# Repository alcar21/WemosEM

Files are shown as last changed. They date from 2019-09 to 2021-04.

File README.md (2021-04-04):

# WemosEM

:warning::warning::warning: **Sorry, I have no time to work on this project. I am involved in new projects** :warning::warning::warning:

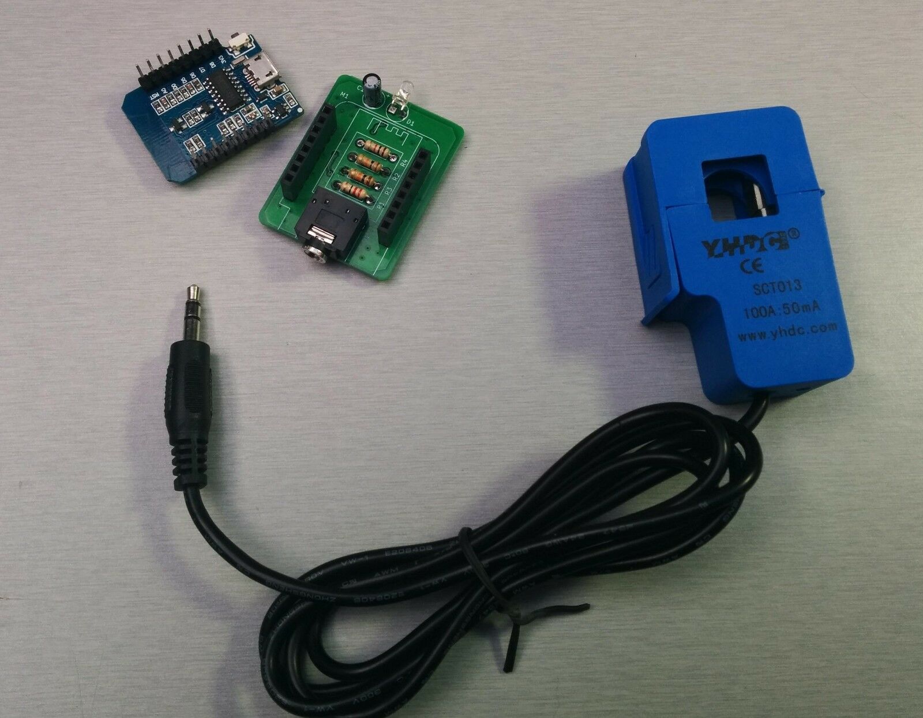
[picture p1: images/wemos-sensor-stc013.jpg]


This is a fork of [@nephiel](https://github.com/Nephiel/MQTT-Power-Sensor) and [@Mottramlabs](https://github.com/Mottramlabs/MQTT-Power-Sensor) projects

Thanks to Dawies [www.domology.es](https://domology.es/medidor-de-consumo-no-invasivo-con-sct013-wemos-d1/) for his contributions and his tutorial

The sensor uses a Wemos D1 Mini and PRO and a Non-invasive Split Core Current Transformer type 100A SCT-013-000, available on eBay.
You can use Current Transformer type calibrated SCT-013-030 (30A), SCT-013-050 (50A) and others. Recomended Clamp 30A or higger.

The sensor samples the current value every 10 seconds and publishes it to a topic via an MQTT broker. you can change this value up to 5 seconds
If the connection fails, it attempts to reconnect to the WiFi and/or the MQTT Broker as needed.

Original Gerber files for the PCB layout and the source files for Kicad are included, although there may be issues with the custom libraries used.

**Software features:**

- Easy setup.
- Responsive design.
- Home Asisstant Discovery.
- All setup in web browser: Wifi, MQTT, Calibrate, timezone, update and system.
- Update Voltaje by MQTT topic.
- NTP to setup timezone.
- Blynk Integration
- ThingSpeak integration
- OTA updates
- Optional reset Kwh counter one day of the month
- Reset Kwh in MQTT Topic

#### Components: 
- Wemos D1 Mini / D1 Mini Pro
- [ESP8266 Mains Current Sensor](https://www.ebay.es/itm/ESP8266-Mains-Current-Sensor-Wemos-Current-transformer-SCT013-100A-50mA/133077015640)
- Current transformer SCT013 (Ebay or Aliexpress)
- Optional case: https://www.thingiverse.com/thing:3544702

**WARNING:** If you use calibrated clamp, **REMOVE resistance R1** from mains current sensor.

## Firmware installation and first setup

#### Flashing: 

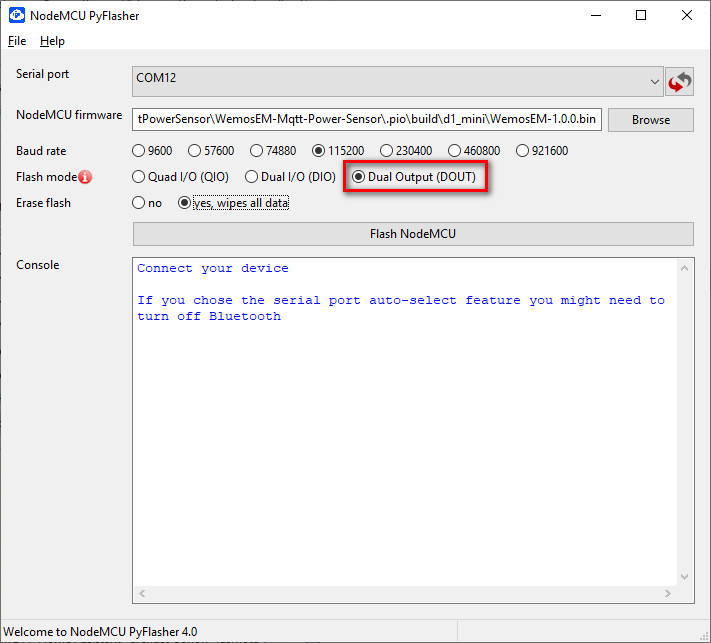
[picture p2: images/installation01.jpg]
installation01


Download latest [release](https://github.com/alcar21/WemosEM/releases)
You can flash using software [nodemcu-pyflasher](https://github.com/marcelstoer/nodemcu-pyflasher/releases)

1. Select Serial port (COM# port) where your serial-to-USB or NodeMCU/D1 mini is connected. Leave on auto-select if not sure.
2. Browse to the binary you downloaded from WemosEM releases.
3. Set Baud rate to 115200 and **Flash mode to DOUT**. Erase flash to **yes** if it is the first time flashing WemosEM on the device or you're experiencing issues with existing flash. If you're upgrading WemosEM set to no.
4. Click Flash NodeMCU and watch the progress in console.

If the flash was successful the console will display:
  Firmware successfully flashed. unplug/replug or reset device to switch back to normal boot mode

Unplug your adapter or device and plug it back in or connect to another power source. Your device is now ready for Initial configuration.

You can see in Tasmota project other options to flash: https://github.com/arendst/Sonoff-Tasmota/wiki/Flashing

#### Initial configuration

WemosEM provides a wireless access point for easy Wi-Fi configuration.

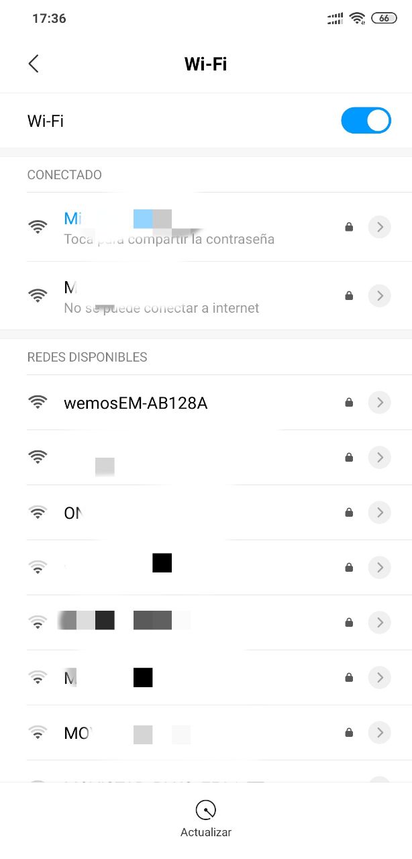
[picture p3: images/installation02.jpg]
installation02

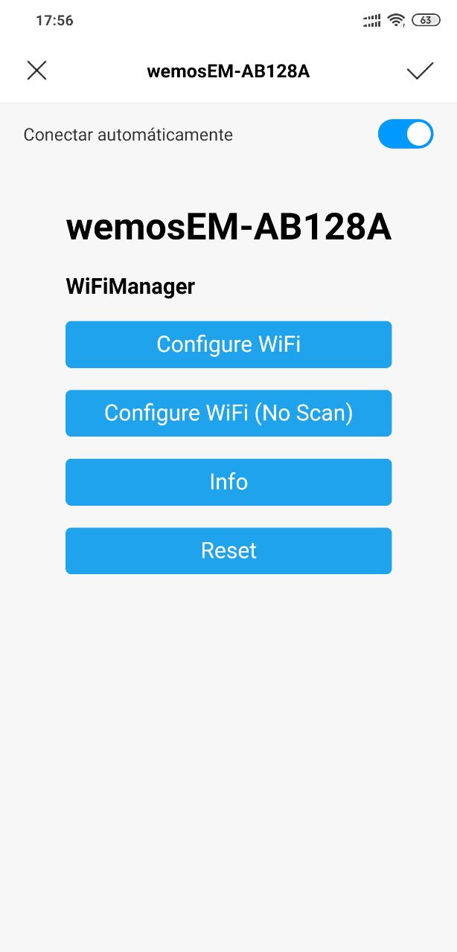
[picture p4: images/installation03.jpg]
installation03

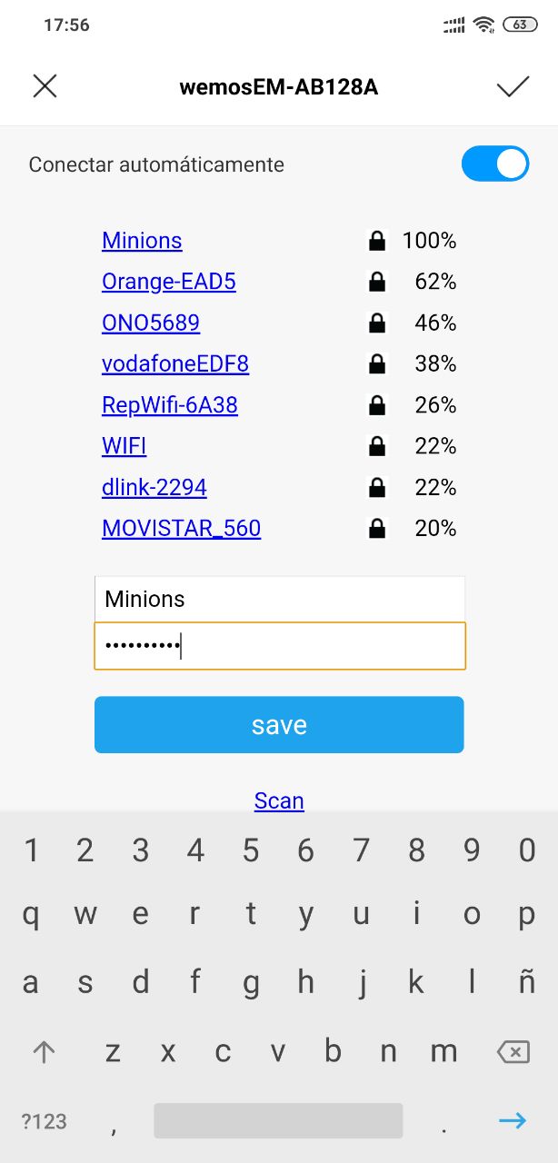
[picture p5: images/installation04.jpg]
installation04


Connect your device to a power source and grab your smartphone (or tablet or laptop or any other web and Wi-Fi capable device). Search for a Wi-Fi AP named **wemosEM-xxxxxx** (where x is a last part of MAC) and connect to it with password **infinito&masalla**. In this example the Wi-Fi AP is named **wemosEM-AB128A**. When it connects to the network, you may get a warning that there is no Internet connection and be prompted to connect to a different network. Do not allow the mobile device to select a different network.

After you have connected to the WemosEM Wi-Fi AP, open http://192.168.4.1 in a web browser on the smartphone (or whatever device you used). Some devices might prompt you to sign in to Wi-Fi network which should also open the above address.

At this page you can have WemosEM scan for available Wi-Fi networks. Select and setup you wifi network. Click save and you wemos will connect to your wifi.

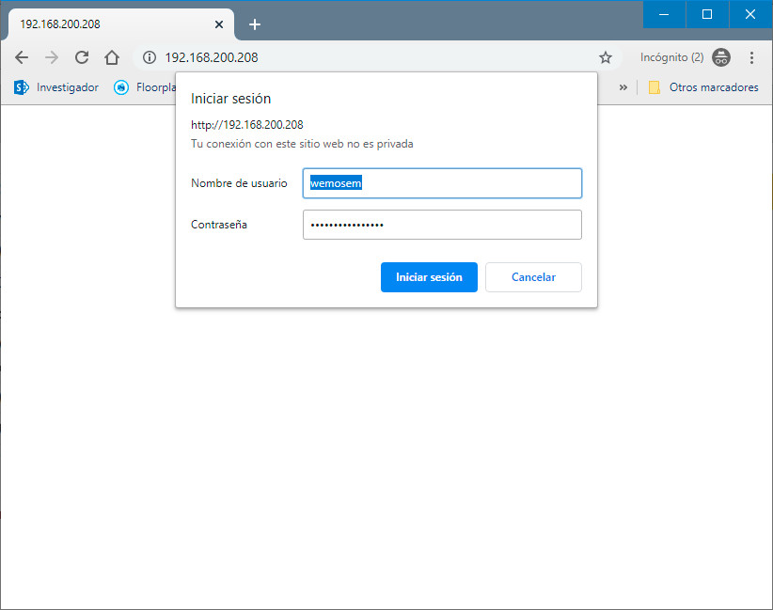
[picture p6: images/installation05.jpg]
installation05

Finally, connect with IP or http://wemosem-xxxxxx.local/ and enter default user and passwor:

* **Default user: wemosem**
* **Default password: infinito&masalla**

Password is updatable in configuration system tab.

## Ical Value

you can view the ICAL value in http://lechacal.com/wiki/index.php/Current_Transformer_Conditioner

CT | Output Type | Rburden | Rgain (for 5V) | ICAL (for 5V) | Rgain (for 3.3V) | ICAL (for 3.3V)
-- | -- | -- | -- | -- | -- | --
SCT-013-005 | Voltage | None | 130 kΩ | 2.83 | None* | 5.0
SCT-013-010 | Voltage | None | 130 kΩ | 5.66 | None* | 10.0
SCT-013-015 | Voltage | None | 130 kΩ | 8.49 | None* | 15.0
SCT-013-020 | Voltage | None | 130 kΩ | 11.31 | None* | 20.0
SCT-013-025 | Voltage | None | 130 kΩ | 14.14 | None* | 25.0
SCT-013-030 | Voltage | None | 130 kΩ | 16.96 | None* | 30.0
SCT-013-050 | Voltage | None | 130 kΩ | 28.28 | None* | 50.0
SCT-013-060 | Voltage | None | 130 kΩ | 33.94 | None* | 60.0
  |   |   |   |  
SCT-006 | Current | 10 Ω | 17 kΩ | 11.62 | 28 kΩ | 17.5
SCT-013-000 | Current | 10 Ω | 40 kΩ | 56.57 | 75 kΩ | 85.71
SCT-019 | Current | 10 Ω | 24 kΩ | 116.13 | 40 kΩ | 171.43

## Setup in Home Assistant (without MQTT autodiscovery)
    
    sensor:
    - platform: mqtt
      state_topic: "wemos/wemosEM-XXXXXX/power"
      name: WemosEM-Amperaje
      icon: mdi:current-ac
      unit_of_measurement: "A"
      value_template: "{{ value_json.current }}"
    - platform: mqtt
      state_topic: "wemos/wemosEM-XXXXXX/power"
      name: WemosEM-Consumo Actual
      icon: mdi:power-plug
      unit_of_measurement: "W"
      value_template: "{{ value_json.watios }}"
    - platform: mqtt
      state_topic: "wemos/wemosEM-XXXXXX/power"
      name: WemosEM-KWh
      icon: mdi:power-plug
      unit_of_measurement: "KWh"
      value_template: "{{ value_json.kwh }}"nt Cell  | Content Cell  |

## Update Voltaje with Home Assistant

if you have a Shelly EM, add a automation in Home assistant:
      
      - alias: Update voltage WemosEM
        initial_state: 'on'
        trigger:
        - platform: mqtt
          topic: shellies/shellyem-B9E2E9/emeter/0/voltage
    
        action:
        - service: mqtt.publish
          data_template:
            topic: "wemos-cmd/wemosEM-XXXXXX/voltage"
            payload: '{{ trigger.payload }}'

if you have a device with Tasmota, add a automation in Home assistant:

      - alias: Update voltage Tasmota-WemosEM
        initial_state: 'on'
        trigger:
        - platform: mqtt
          topic: tele/sonoff01/SENSOR

        action:
        - service: mqtt.publish
          data_template:
            topic: "wemos-cmd/wemosEM-XXXXXX/voltage"
            payload: "{{ trigger.payload_json['ENERGY'].Voltage }}"

## Blynk Integration

Go to Blynk app on your phone and layout the blynk project with virtual pin number according:
- Virtual PIN V0: Voltage (V)
- Virtual PIN V1: Current (A)
- Virtual PIN V2: Live Watios (w)
- Virtual PIN V3: Energy (kwh)
- Virtual PIN V4: Energy before last reset (kwh)

Setup in web interface token auth, optional you can setup server and port server.

## Thingspeak Integration
Setup in web interface token auth (Write API Key) and Channel number. 
- Field 1: Voltage (V)
- Field 2: Current (A)
- Field 3: Live Watios (w)
- Field 4: Energy (kwh)
- Field 5: Energy before last reset (kwh)

## MQTT Topics
Topic  | Description
------------- | -------------
wemos-cmd/wemosEM-XXXXXX/voltage | Set/update voltage (from sonoff, shelly or other devices)
wemos-cmd/wemosEM-XXXXXX/status | Get Status of wemosEM
wemos-cmd/wemosEM-XXXXXX/resetkwh | reset kwh and store and beforeResetkwh variable

## OTA Updates
OTA updates from platformio windows with espota:
~/.platformio/packages/tool-espotapy/espota.py --progress --ip 192.168.4.1 --auth "infinito&masalla" --file wemosEM-1.3.1_core-2.4.bin

## Developers
This project is developed with **platformio**. WemosEM not compile with core 2.3 because blynk library require core 2.4.0 or higher.
- Recomended compile this project with Arduino Core 2.4.2.

**Commands:**
- Compile: pio run
- Compile and upload Wemos D1: pio run -t upload

Other options:
- Compile with core 2.5: pio run -t upload -e d1_mini_2_5
- Compile for Wemos D1 Mini PRO (**only core 2.4**): pio run -t upload -e d1_mini_pro_2_4

## Tests

## Screenshots

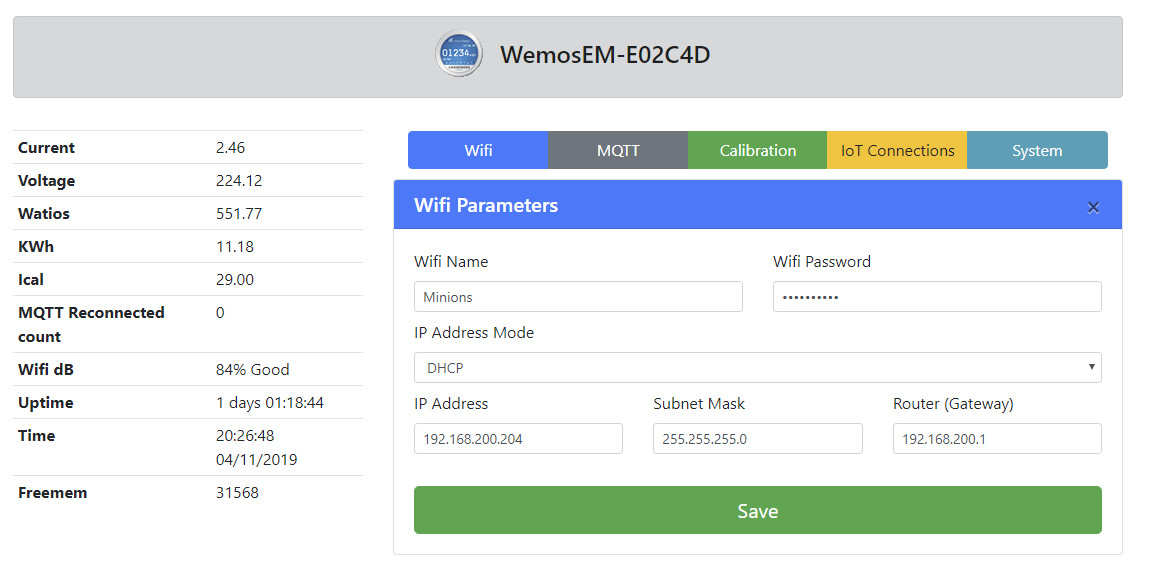
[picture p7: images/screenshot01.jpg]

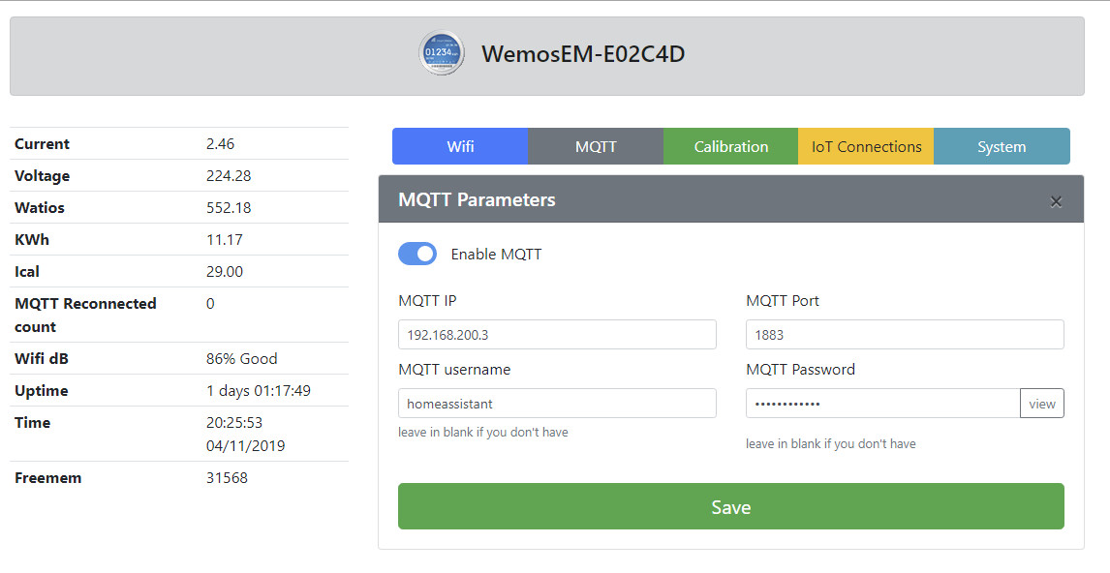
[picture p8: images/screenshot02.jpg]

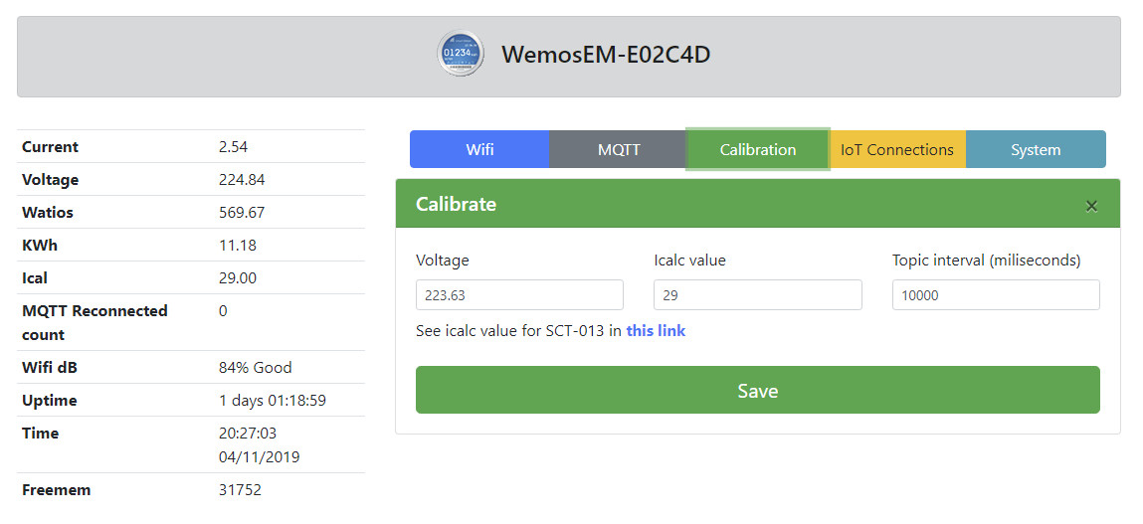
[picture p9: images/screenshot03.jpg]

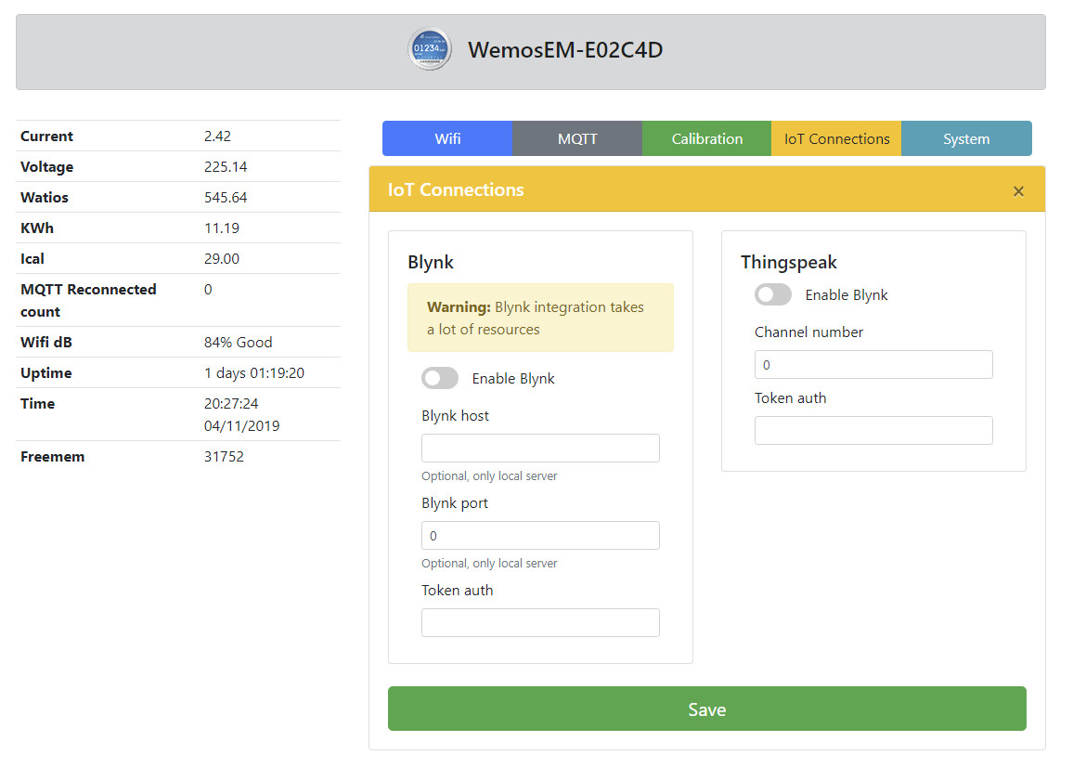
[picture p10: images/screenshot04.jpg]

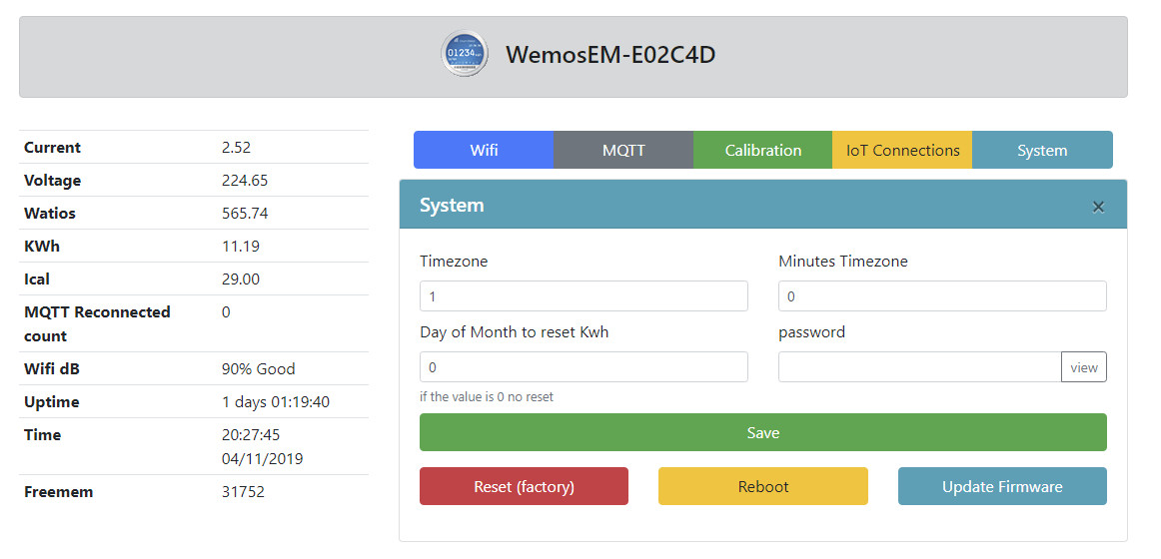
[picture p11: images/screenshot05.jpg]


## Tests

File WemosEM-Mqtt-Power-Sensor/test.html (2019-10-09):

#### WemosEM-000000

Current | 0.00
Voltage | 0.0
Watios | 0.00
KWh | 0.00
Ical | 0.00
MQTT Reconnected count | 0
Wifi dB | 0
Uptime | 0 days 00:00:00
Time | 00:00:00 00/00/0000
Freemem | 0

Wifi MQTT Calibration Time System

##### Wifi Parameters

Wifi Name

Wifi Password

IP Address Mode

IP Address

Subnet Mask

Router (Gateway)

Save

##### MQTT Parameters

Enable MQTT

MQTT IP

MQTT Port

MQTT username leave in blank if you don't have

MQTT Password

view

leave in blank if you don't have

Save

##### Calibrate

Voltage

Icalc value

Topic interval (miliseconds)

See icalc value for SCT-013 in this link (http://lechacal.com/wiki/index.php/Current_Transformer_Conditioner)

Save

##### Time

Timezone

Minutes Timezone

Save

##### System

password

view

Save

Reset (factory)

Reboot

Update Firmware

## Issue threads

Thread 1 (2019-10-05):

platformio compile problems

dpavlin, 2019-10-05:
First, thanks for such a nice project. I'm having problems compiling using PlatformIO, version 4.0.3 (which is currently latest). When using (default) platform_150 it doesn't fit:

```
/home/dpavlin/.platformio/packages/toolchain-xtensa@1.40802.0/bin/../lib/gcc/xtensa-lx106-elf/4.8.2/../../../../xtensa-lx106-elf/bin/ld: .pio/build/d1_mini/firmware.elf section `.text' will not fit in region `iram1_0_seg'
collect2: error: ld returned 1 exit status
*** [.pio/build/d1_mini/firmware.elf] Error 1
```

And when compiling with all others I get:

```
Setup finished

Exception (3):
epc1=0x4021c03c epc2=0x00000000 epc3=0x00000000 excvaddr=0x4025c5d7 depc=0x00000000
```
And esp keeps rebooting.

Your release binary does work for me, so I'm wondering how did you compile it?

alcar21, 2019-10-07:
Please, compile with platform_180. I fix as soon as possible.
In the current download of the arduino versions two files are missing. You can download them from here: https://github.com/esp8266/Arduino/tree/2.3.0/tools/sdk/ld
The files are: eagle.flash.4m3m4s.ld and eagle.app.v6.common.ld
I will correct it later.

alcar21, 2019-10-07:
Sorry, fixed in master branch.

Closed 2019-10-07.

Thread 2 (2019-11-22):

MQTT not publishing

afly007, 2019-11-22:
I'm having issues with MQTT and home assistant.  The only message that the MQTT broker receives from wemosEM is a status offline message, even though the logs show it's publishing correctly.

I have everything configured as instructed in the Readme, any ideas?

Thanks

Status MQTT: -3 Reconnecting...
 Attempting MQTT Broker connection... Reconnecting with user/pass
 MQTT Connected.
Preparing topic HA Discover
Preparing message HA Discover
 [METER] - Payload: {"current":"0.00","voltage":"5.00","watios":"0.00","kwh":"0.02","beforeKwh":"0.00","ical":"85.71","mqttreconnected":"2","wifidb":"56% Bad","uptime":"   0 days 00:02:32","time":"11:36:30 22/11/2019","freemem":23928}
 [MQTT] - Published: wemos/wemosEM-51F13F/power > {"current":"0.00","voltage":"5.00","watios":"0.00","kwh":"0.02","beforeKwh":"0.00","ical":"85.71","mqttreconnected":"2","wifidb":"56% Bad","uptime":"   0 days 00:02:32","time":"11:36:30 22/11/2019","freemem":23928}
 [MQTT] - Published: wemos/wemosEM-51F13F/status > online [METER] - rmsCurrent: 0.00 mainsVoltage: 5.00 Watios: 20.36 kwh: 0.02 Before reset kwh: 0.00 lastTimeMeasure: 147133
SAVED CONFIG: {"wifi_name":"","wifi_password":"","ip_mode":0,"ip":"192.168.0.43","mask":"255.255.255.0","gateway":"192.168.0.1","mqtt_enabled":true,"mqtt_server":"192.168.0.6","mqtt_port":1883,"mqtt_username":"wemosem","mqtt_password":"wemosem","message_interval":10000,"voltage":5,"ical":85.71,"blynk_enabled":false,"blynkAuth":"","blynkServer":"","blynkPort":0,"ts_enabled":false,"tsChannelNumber":0,"tsWriteAPIKey":"","timezone":7,"minutes_timezone":0,"system_password":"infinito&masalla","dayReset":0,"watiosTotal":20.35835,"kiloWattHours":0.020358,"beforeResetKiloWattHours":0}
[BLYNK] Disabled
[THINGSPEAK] Disabled
 [METER] - Payload: {"current":"0.00","voltage":"5.00","watios":"0.00","kwh":"0.02","beforeKwh":"0.00","ical":"85.71","mqttreconnected":"2","wifidb":"60% Poor","uptime":"   0 days 00:02:37","time":"11:36:35 22/11/2019","freemem":26200}
 [MQTT] - Published: wemos/wemosEM-51F13F/power > {"current":"0.00","voltage":"5.00","watios":"0.00","kwh":"0.02","beforeKwh":"0.00","ical":"85.71","mqttreconnected":"2","wifidb":"60% Poor","uptime":"   0 days 00:02:37","time":"11:36:35 22/11/2019","freemem":26200}
 [MQTT] - Published: wemos/wemosEM-51F13F/status > online

Output from Home Assistant MQTT listener...

 Message 18 received on wemos/wemosEM-51F13F/status at 11:39 PM:

Offline

QoS: 0 - Retain: false
Message 17 received on wemos/wemosEM-51F13F/status at 11:39 PM:

Offline

QoS: 0 - Retain: false
Message 16 received on wemos/wemosEM-51F13F/status at 11:38 PM:

Offline

QoS: 0 - Retain: false
Message 15 received on wemos/wemosEM-51F13F/status at 11:37 PM:

Offline

QoS: 0 - Retain: false
Message 14 received on wemos/wemosEM-51F13F/status at 11:36 PM:

Offline

alcar21, 2019-11-22:
Hello,
what version do you have installed?
- WemosEM-1.3.1-core_2.4.bin?
- WemosEM-1.3.1-core_2.5.bin?

Do you have the discover on home assistant enabled?

Thanks.

Closed 2019-12-31.

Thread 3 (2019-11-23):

MQTT not enabled after reboot

mason-xx, 2019-11-23:
Flashed WemOS D1  mini with WemosEM-1.3.1-core_2.5.bin. Configured and enabled MQTT on the Webif. Working fine. But after disconnect the Wemos aka reboot it, MQTT stays disabled and need to be reenabled by the webif to work again.

Expected behaviour would be to stay activated after a reset/reboot of the controller.

alcar21, 2019-11-23:
Please, use version WemosEM-1.3.1-core_2.4.bin.
The arduino 2.5 core has problems with the Wifi controller. I have read it on the [Tasmota website](https://github.com/arendst/Tasmota/releases) **search** "Core version 2.3.0 vs 2.4.2 vs 2.5.2"

The core 2.4 in this firmware working fine. Please, can you attach the logs if you know how to obtain them?

> Expected behaviour would be to stay activated after a reset/reboot of the controller.
yes, this is how it works for me with WemosEM-1.3.1-core_2.4.bin. I honestly haven't tried the version with core 2.5.

Thank you.

mason-xx, 2019-11-23:
You want the logs of the 2,5 version or the 2.4?

alcar21, 2019-11-23:
The test performed by other developers, the version 2.4 is usually more stable. The best core is 2.3 but there are libraries that use firmware that does not support 2.3.
You can attach the logs of the version you want but I recommend you use the 2.4

mason-xx, 2019-11-23:
Here is a log from 2.5 https://hastebin.com/awoqifehiz.cs not much in there..
But after reflashing with 2.4 mqtt stays enabled after a reboot as expected... thank you! :)

alcar21, 2019-11-24:
Great!
Log is only necessary when the problem occurs but it is fully proven to fail.
Thank you very much.

Closed 2019-11-24.

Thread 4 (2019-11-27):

Domoticz integration

InvertedMinor, 2019-11-27:
Could you provide a Domoticz integration via MQTT?

alcar21, 2019-11-28:
Ok, I Try. I have not Domoticz .

InvertedMinor, 2019-11-28:
Great:  https://www.domoticz.com/wiki/MQTT

alcar21, 2019-11-28:
it is easy. Please, Can you do beta tester??
Thanks!

InvertedMinor, 2019-11-29:
of course!

asem67, 2019-12-31:
Could you provide a Domoticz integration via MQTT
or IoT Connections >> [Domoticz API](https://www.domoticz.com/wiki/Domoticz_API/JSON_URL%27s#Electricity_.28instant_and_counter.29)

Thanks !

alcar21, 2019-12-31:
Hello,
I'm working in it. in the next few days I will release a version compatible
with domoticz
Thanks

El mar., 31 dic. 2019 18:23, asem67 <notifications@github.com> escribió:

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

pepijnkoopman, 2020-01-12:
Looking forward to the Domoticz integration via MQTT! When it's is ready I would like to beta test as well.

RichieRogers, 2020-05-11:
Hi,
It looks like development has stopped on this :(
Has anyone successfully integrated this with Domoticz (ideally with MQTT)?
If so, can you supply the firmware or what modifications i need to make to WemosEM to get this working?

Thanks,
Richie

pepijnkoopman, 2020-05-11:
Hi Richie, I integrated WemosEM with Domoticz using **MQTT + Node-RED**. WemosEM publishes the data on a MQTT server (Mosquitto). A Node-RED script subscribes to these messages on Mosquitto server, converts them to messages for Domoticz and publishes the messages to the domoticz/in topic of the MQTT server of Domoticz. More information: https://www.domoticz.com/wiki/MQTT

RichieRogers, 2020-05-11:
Ahh, ok.
I'm running Domoticz and Mosquitto on a Windows environment, so will look at installing Node-Red as well (no experience of Node-Red so will be interesting getting this working).

Thanks,
Richie

pepijnkoopman, 2021-05-26:
Hi @daniel-dms, below is the export of my Node-Red flow:
`[{"id":"3f2dd754.b751f","type":"tab","label":"PowerMon1 Current","disabled":false,"info":""},{"id":"40a67cbc.ee3d74","type":"mqtt in","z":"3f2dd754.b751f","name":"","topic":"wemos/wemosEM-239E74/power","qos":"0","datatype":"auto","broker":"bbc5f10.1ab581","x":170,"y":60,"wires":[["da04248a.acb1a"]]},{"id":"da04248a.acb1a","type":"json","z":"3f2dd754.b751f","name":"","property":"payload","action":"","pretty":false,"x":350,"y":220,"wires":[["a14cc7d1.c7e93"]]},{"id":"a14cc7d1.c7e93","type":"function","z":"3f2dd754.b751f","name":"Get current","func":"var value = msg.payload.current;\nmsg.payload = value;\nreturn msg;","outputs":1,"noerr":0,"x":530,"y":220,"wires":[["9769d2ff.7a808","f3521a2e.f786e8"]]},{"id":"709c2826.f4fb28","type":"mqtt out","z":"3f2dd754.b751f","name":"","topic":"domoticz/in","qos":"","retain":"","broker":"72fca658.733588","x":1030,"y":60,"wires":[]},{"id":"e750ff81.9554d","type":"debug","z":"3f2dd754.b751f","name":"","active":true,"tosidebar":true,"console":false,"tostatus":false,"complete":"payload","targetType":"msg","x":990,"y":300,"wires":[]},{"id":"9769d2ff.7a808","type":"debug","z":"3f2dd754.b751f","name":"","active":false,"tosidebar":true,"console":false,"tostatus":false,"complete":"payload","targetType":"msg","x":690,"y":300,"wires":[]},{"id":"f3521a2e.f786e8","type":"function","z":"3f2dd754.b751f","name":"Add Domoticz IDX 33 (PowerMon1Current)","func":"var current = msg.payload;\n\nmsg.payload = {};\nmsg.payload.svalue = current;\nmsg.payload.idx = 33;\nreturn msg;","outputs":1,"noerr":0,"x":870,"y":220,"wires":[["e750ff81.9554d","709c2826.f4fb28"]]},{"id":"bbc5f10.1ab581","type":"mqtt-broker","name":"SDRPi","broker":"192.168.2.31","port":"1883","clientid":"","usetls":false,"compatmode":true,"keepalive":"60","cleansession":true,"birthTopic":"","birthQos":"0","birthPayload":"","closeTopic":"","closePayload":"","willTopic":"","willQos":"0","willPayload":""},{"id":"72fca658.733588","type":"mqtt-broker","name":"","broker":"192.168.2.48","port":"1883","clientid":"","usetls":false,"compatmode":false,"keepalive":"15","cleansession":true,"birthTopic":"","birthQos":"0","birthPayload":"","closeTopic":"","closePayload":"","willTopic":"","willQos":"0","willPayload":""}]`

daniel-dms, 2021-05-26:
THANKS.........IT'S WORKING

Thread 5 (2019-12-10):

Differences between SCT-013-000

silbopower, 2019-12-10:
Hi alcar21, first of all, great work! I'm going to use it ASAP but I have a dubt.
What is the difference using a 30A transformer or a 50A one?
Could I also use freely a 15A or I have to modify some configuration (sw/hw)?
Thank you
S

alcar21, 2019-12-10:
Hello,
Thank :smiley:. yes, you can perfectly use the 50A, 30A or 15A transformer. There is no problem. Only the calibration changes in the "Ical Value" section

silbopower, 2019-12-11:
Great! I'll try as soon as components arrive!
Thanks again

Closed 2019-12-31.

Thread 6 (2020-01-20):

A couple of minor items and a question

NorthernMan54, 2020-01-20:
Tks for this piece of work, it is very well done.  I just have a couple of minor things

1 - I'm in North America and I can't set the timezone to -5 ( Eastern Standard )

2 - When the device reboots, the data is wonky for the first minute, can this false data be thrown away?  ie call em_read(true); at the end of the setup function?

3 - When Power usage is zero, the current sits between 0.02 to 0.04, any thoughts on why?

4 - Noticed that after running for 24 hours, this message "Failed to open config file for writing", so am wondering why the em_read is writing the config after every read in WiFi station mode.

For setup, I'm using a SCT013 Calibrated at 30A 1V, local power is 120 volt 60 Hertzs

alcar21, 2020-01-22:
Hello, thanks.

1. Ok, i will fix in next version.
2. It's difficult, when system start, it perform a calibration and discard initials values. I could add an option in configuration that discard data of a period of time
3. It is the rounding of precision, it will really count for example 0.004 watts
4. Which version are you using? Please use the core 2.4

The measured is correctly? Thanks by the report.
Please be patient, my dedication time to the project is very short.

NorthernMan54, 2020-01-22:
For these, I'm putting together a pull request and fix for the MQTT Issue

I'm just testing behaviour when WiFi drops and restarts, then I will submit

alcar21, 2020-01-22:
Thank you.

Un saludo,
Alfonso C.

El jue., 23 ene. 2020 a las 0:20, Northern Man (<notifications@github.com>)
escribió:

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

NorthernMan54, 2020-01-23:
Please review pull request #8

alcar21, 2020-01-23:
Accepted. Thanks.

NorthernMan54, 2020-01-23:
Tks

Closed 2020-01-23.

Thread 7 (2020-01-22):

MQTT gets disabled after a reboot

amoros1, 2020-01-22:
Congrats for the nice piece of work!

I found that after enabling MQTT and saving in the MQTT parameters, when the Wemos restarts, the MQTT gets disabled so you need to enter again in the UI to enable it. I wonder if there is some issue with the enable flag that after a reboot it is set again to disable?.
Could be this behavoir the way this function was designed to work?,

Many thanks
Luis

alcar21, 2020-01-22:
:smirk: yes, this error has been reported by other people in private. I'm working in it.

if yoy want try, in the previous version if it works correctly, I am checking it.

Thanks, regards.

amoros1, 2020-01-24:
Thanks. Yes, I will make the test
Regards

plutec, 2020-04-06:
Are working in the previous version? Did you fix it in the new one?

Thanks!

alcar21, 2020-04-06:
Sorry, I have yet to release the patch. This week i try it.

PaulHam211, 2020-04-21:
Hey, Any chance of releasing the patch for this? I have set up my device today and have noticed that MQTT disables after a reset.
I considered trying to build a version with MQTT enabled in code however I struggled to build in Atom (mac equivalent of Platform IO) and now I assume this is a bug and enabling MQTT automatically wont actually fix it?

nandosof, 2020-05-14:
have fix?? thank you!

alcar21, 2020-06-02:
Sorry, I will release a version this weekend.

I don't have much time to dedicate to the project.

Thanks you

PaulHam211, 2020-06-21:
Sorry @alcar21  I know your busy but any luck with this MQTT enable on boot fix?

plutec, 2020-07-06:
Fixed in code, I just compile for Core 2.4. I didn't check yet in my hardware.

https://mega.nz/file/eRknmQKQ#T9rFCZ6qjTx1qB8fpxCNPB3yId9L3Dg5LpY-535Yt5k

plutec, 2020-07-06:
I just checked in my wemos and at least it saves the MQTT after restart. So this flaw can be considered as solved.

nandosof, 2020-07-06:
Work fine. Thanks for your work!

rechena, 2020-10-04:
I can confirm that on the latest version this issue still happens :(

plutec, 2020-11-01:
@rechena is your issue related with MQTT or with WiFi connection? Please, take a look to this PR: https://github.com/alcar21/WemosEM/pull/16

rechena, 2020-11-01:
> @rechena is your issue related with MQTT or with WiFi connection? Please, take a look to this PR: #16

My issue is with MQTT, when I restart the device MQTT goes back to disabled :(

plutec, 2020-11-01:
Did you try with the version I shared un this issue?

El dom., 1 nov. 2020 15:52, Joao Rechena <notifications@github.com>
escribió:

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

plutec, 2020-11-02:
@rechena please, update with this version: https://mega.nz/file/eRknmQKQ#T9rFCZ6qjTx1qB8fpxCNPB3yId9L3Dg5LpY-535Yt5k
And then, configure the MQTT again. For me it's working perfectly.

rechena, 2020-11-03:
> @rechena please, update with this version: https://mega.nz/file/eRknmQKQ#T9rFCZ6qjTx1qB8fpxCNPB3yId9L3Dg5LpY-535Yt5k
>
> And then, configure the MQTT again. For me it's working perfectly.

Oh will give it a try. Can I use the OTA feature? Or do I need to plug cable? Thanks

plutec, 2020-11-03:
With OTA is ok

El mar., 3 nov. 2020 7:29, Joao Rechena <notifications@github.com> escribió:

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

rechena, 2020-11-03:
Yay, just updated using OTA and its working just fine, didn't even have to reconfigure MQTT :) Thanks

plutec, 2020-11-03:
@alcar21 you can close this issue. Thanks!

alcar21, 2020-11-08:
Thank you. Fix in version 1.3.2

Closed 2020-11-08.

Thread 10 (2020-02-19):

Power monitoring for 3 phase

selahattinerdal, 2020-02-19:
@alcar21
Could you provide power monitoring for 3 phase.
Maybe with ESP32, MCP3008 or ADS1115.
Thanks.

alcar21, 2020-06-02:
I will try when I have time. I am focusing my efforts on also supporting the PZEM-004T which is much more accurate, I have an already operational version.
Lately I have little time to dedicate to the project.
I received your code, thank you very much!

alcar21, 2020-11-08:
I have no time. I received your code but I will have to see.
Thank you very much.

selahattinerdal, 2020-11-08:
I thank you.

Closed 2020-11-08.

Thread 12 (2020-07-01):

1v vs 3.3v

buzzy, 2020-07-01:
How did you solve the fact that the CT outputs 0-1v and the Wemos D1 has a built-in voltage divider on the ADC that allows 0-3.3v on the ADC? If you don't boost the CT output, you will only use 1/3 of the resolution of the ADC, giving you only 333 steps between 0A and 30A, about 0.1A steps, which would mean 22W "resolution". Please advice.

rechena, 2020-10-04:
Would this cause the power consumption to be reported way lower than expected? For e.g a 2500W being reported as ~500W for example? Thanks

alcar21, 2020-10-05:
The ADC of ESP8266 is 0-1v please read the documentation:
https://arduino-esp8266.readthedocs.io/en/latest/reference.html

A good improvement will be using the ADC of ADS115 that it has 0-5v. I am
working on a version that it's better and it uses the module PZEM-004T.

Un saludo,
Alfonso C.

El dom., 4 oct. 2020 a las 15:00, Joao Rechena (<notifications@github.com>)
escribió:

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

Closed 2020-11-08.

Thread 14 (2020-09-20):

Monitor the Mains?

rechena, 2020-09-20:
Can I use this board code to monitor my house at the mains board? Thanks

alcar21, 2020-09-20:
yes of course.

Un saludo,
Alfonso C.

El dom., 20 sept. 2020 a las 18:55, Joao Rechena (<notifications@github.com>)
escribió:

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

rechena, 2020-09-21:
Thanks for the reply. I had a old system using an arruino uno and Xbee but this makes it so much better :)
One thing though on mine I was measuring using an AC/AC transformer for the current, would it be possible to do the same somehow on yours? Thanks

alcar21, 2020-10-01:
Yes, you can measure AC by putting the clamp on one phase. You only need a transformer to power the ESP8266

rechena, 2020-10-02:
Thanks I was more asking about using this approach - https://learn.openenergymonitor.org/electricity-monitoring/ctac/how-to-build-an-arduino-energy-monitor. But That would need some changes on the board.
Regardless, do you have any link to help with the calculation of the icalc? Thanks

alcar21, 2020-10-02:
Yes, please, visit this url:
http://lechacal.com/wiki/index.php/Current_Transformer_Conditioner

Un saludo,
Alfonso C.

El vie., 2 oct. 2020 a las 12:02, Joao Rechena (<notifications@github.com>)
escribió:

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

rechena, 2020-10-04:
Hi, I'm a bit confused on whats happening, I finally got around to install this, ufortunately I had to install the CT on the Neutral since the Live is too short, regardless, from what I read it won't make a difference.
The concern is, looking at the house in "standby" I'm reading around 146W, which I love it being so low, but.. when I turn on my kettle which is 2500/3000W, the Watts only increase to 568W... I have a SCT-013-030 and I've calibrated the iCalc to 30.0... I've measured my Voltage with a Multimeter and its giving me 233V.

Can you think if anything I might be doing wrong?

Thanks

alcar21, 2020-10-05:
yes, all ok. it's strange.

Please, Can you probe a toaster or a hair dryer?

Thank you.

El dom., 4 oct. 2020 a las 13:52, Joao Rechena (<notifications@github.com>)
escribió:

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

rechena, 2020-10-05:
I would gladly but unfortunately it was so hard to had the CT to the main's board that if I remove it it will break :( need to order a new one and then I can test. I was just wondering if you noticed something similar... Guess I need to buy a new CT and test it... :(

alcar21, 2020-10-05:
it's not necessary. You connect the hairdryer o the toaster in a socket and
test.

El lun., 5 oct. 2020 a las 9:54, Joao Rechena (<notifications@github.com>)
escribió:

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

rechena, 2020-10-05:
I've just tested both ways, with the socket and directly with just the hairdryer, and its reporting only ~400W for a 1800-2200W hairdryer :(

![Uploading IMG_6901.JPG…]()

alcar21, 2020-10-05:
Please, Can you post images of your configuration?

rechena, 2020-10-05:
Of the d1mini and all the components?

alcar21, 2020-10-05:
Only configuration calibration tab of wemos d1 mini. this:

[image: image.png]

El lun., 5 oct. 2020 a las 12:11, Joao Rechena (<notifications@github.com>)
escribió:

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

alcar21, 2020-10-05:
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

rechena, 2020-10-05:
Sure :)
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

btw, I've measured the Voltage with a multimeter on a wall plug.

alcar21, 2020-10-05:
oook, CT is 0-1v or 0-5v?

rechena, 2020-10-05:
It's the SCT-013-030...so from the specs its 0-1v? I did used in the past with a 5V Arduino, not sure if it helps.

alcar21, 2020-10-05:
Arduino works with 5v and ADC of ESP8266 work with 1v. This board is calibrated for the ADC of the Wemos D1 to range 0-1v.

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

rechena, 2020-10-05:
That is the board I got, I got it from the eBay link you have on this page.. :( and I'm using it with a Wemos D1

alcar21, 2020-10-05:
It's all Ok. Can you post a photo of the connections with Wemos D1, board, and CT?

rechena, 2020-10-05:
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

rechena, 2020-10-05:
I might be wrong, but I find the A/Current value way to low...

alcar21, 2020-10-05:
yes is very low. Sure, this is not well.

I believe that it's the cable of CT (jack 3.5) that connects to the board.
I have a friend that has the same problem but I am not sure.

El lun., 5 oct. 2020 a las 15:11, Joao Rechena (<notifications@github.com>)
escribió:

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

rechena, 2020-10-05:
So you think I might have a bad CT? :(

alcar21, 2020-10-05:
yes, may be

rechena, 2020-10-05:
Ok so not much to do but buy a new one. Any recommendations on the Amp? Should I keep the 30amp or go higher?

alcar21, 2020-10-05:
I recommend to you buying PZEM-004T. I have a firmware that it's compatible with PZEM-004T.
This CT has more precession that SCT-013-30. The SCT-013 is best when it's smaller.

rechena, 2020-10-05:
Does it work with the d1mini and the shield? Do you have a link?

rechena, 2020-10-06:
Was just checking the eBay where o got the board and I think I've figure out the issue. This board is for use with the sct-013-000 so I'm guessing there's an extra burden resistor, I do recall when I was using the openenergy schematics that was the plan. I've just ordered one and will let you know.

alcar21, 2020-10-06:
Indeed, I had not noticed.

WARNING: If you use a calibrated clamp, remove resistance R1 from mains
current sensor.

Un saludo,
Alfonso C.

El mar., 6 oct. 2020 a las 9:11, Joao Rechena (<notifications@github.com>)
escribió:

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

rechena, 2020-10-06:
Don't think mine is calibrated... and wouldn't want to remove  an R1.. so I might just wait for the 000 one to arrive :)

alcar21, 2020-10-06:
you remember that you must modify the ICAL value for STC-013-000. This
current transformer has minor precision

El mar., 6 oct. 2020 a las 9:46, Joao Rechena (<notifications@github.com>)
escribió:

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

rechena, 2020-10-06:
Yep, will make the change which from this link: http://lechacal.com/wiki/index.php/Current_Transformer_Conditioner is 85.71... interesting number... :D

alcar21, 2020-10-06:
jejeje, perfect! I hope that it's will go fine.

Regards,
Alfonso C.

El mar., 6 oct. 2020 a las 10:13, Joao Rechena (<notifications@github.com>)
escribió:

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

rechena, 2020-10-06:
After a chat with the board seller he confirmed that my CT already had a burden resistor, so I've just removed resistor 1 and now I have proper measures :)

Standby: 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

Kettle: 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

alcar21, 2020-10-06:
great!

El mar., 6 oct. 2020 a las 13:43, Joao Rechena (<notifications@github.com>)
escribió:

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

rechena, 2020-10-06:
Thanks for all your help. I'm gonna close the issue :)

sachasmart, 2025-02-02:
Very sorry to open this again, but attempting to get my house connected. I have this flashed to a Wemos D1 mini n1, which has the [Mottrams Lab - MLP191020](https://www.ebay.co.uk/sch/i.html?_nkw=&_armrs=1&_ipg=&_from=&_ssn=mlabs2018) hat. I am using a [100A/50mA CT clamp](https://www.aliexpress.com/item/32231711500.html?spm=a2g0o.order_list.order_list_main.5.2bff1802d1NOaR).

I have this over a cord to my homelab, which should be pulling around ~400W.

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

Closed 2020-10-06.

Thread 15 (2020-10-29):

Relay shield

avm162, 2020-10-29:
I first congratulate you on the work. It works very well to monitor consumption. It would lack a little more precision.
I wanted to know if it is possible to integrate at least one output to be able to put a relay shield. If it could be controlled by mqtt and even depending on some consumption rule it would be fantastic. Thanks anyway if it can't be done.
Greetings.
Sorry for the English, I used Google translator

plutec, 2020-11-01:
Hi @avm162 .
I think than in the hardware device you have enough GPIO to use, but the functionality of the relay is not really related with the purpose of the project. Maybe you can manage that with any other tool (check ESPHome). If your requirement is a bit more complex, you need to jump to HomeAssistant to create automations.

avm162, 2020-11-01:
Hi.  It was to control a relay depending on the consumption, even through
HA, but without having to use another esp.  thanks anyway.

El dom., 1 nov. 2020 3:04, Antonio Sánchez <notifications@github.com>
escribió:

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

plutec, 2020-11-01:
Yes, I understand what you say, but is not the purpose of the firmware. Just waiting to @alcar21 to confirm if wants to include that feature.

alcar21, 2020-11-08:
I understand good. No problem 👍
The problem with precision is because the ESP8266 has an ADC that doesn't allow more precision to be measured.

I am preparing another firmware for PZEM 004T, it is much better.

it's possible to use a relay shield but it's better that you use another system like a Tasmota, Espurna, or EspHome to control this relay shield. Another option is to use one output to connect a contactor.

Now, I have no time. Due to the pandemic, it is difficult for me to spend time on this firmware.

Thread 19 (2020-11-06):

Do I remove the R1 resistor?

Quercus84, 2020-11-06:
I have a SCT-013-030 and my readings are off when using the ICAL proposed on http://lechacal.com/wiki/index.php/Current_Transformer_Conditioner. I need to push the ICAL up to 140 to get something reasonable. However, I was using the firmware from the domology tutorial and my readings were correct with the hardware as is.

I saw that @rechena ended up removing his in this issue #14 but I'm not sure if I should too.

So, do I take it out?

Thanks!

rechena, 2020-11-06:
If you have the same shield as I had yes you need to remove resistor 1 as it's a burden resistor which already exists in the 030. Alternative is to get a 000 ct.

Quercus84, 2020-11-06:
Ok. I'll try that. Hopefully nothing burns :p

With what ICAL did you ended up?

rechena, 2020-11-07:
I ended up with 30ical, one suggestion on the resistor is remove only one
side, so if in the future you buy a 000 you could just solder the resistor
back.
I ended up buying another board and a 000 but mostly because my house often
goes above 30amp. I still get measures with this one but to be more
precise.

Hope it help

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

--
Best,
Joao Rechena

Quercus84, 2020-11-13:
I removed the resistor and the readings improved. However I am still calibrating the system. With an ical of 30 the readings are overestimated. I'll put the final number when I get it.

alcar21, 2020-11-13:
The measurements aren't precise because it has a margin of error, sometimes great.
I recommend that you calibrate the average power that you use at home. For example, if you consume an average of 2kw, perform the calibration with a device that measures more or less that.
The value of Ical 30 is approximate.

Quercus84, 2020-11-13:
I am calibrating using the daily total in kwh. Currently with ical=26 is still a bit high.

Seraf, 2022-08-26:
Hello,

Maybe someone here may help me 🙏🏻
I bought the same 30A model, so I removed the R1 from the shield.
I don't think my current problem is because of this R1, as I tested different wemos and different shields (with and without R1):

* When I start the wemos without the shield, I can access the wifi, access the webserver.
* When I hotplug the shield, I can still access the wemos, but I can't get any relevant result. The led of the shield is off.
* When I boot the wemos with the shield attached, the led of the shield turns on (and the led of the wemos turns off), but I can't access at all the wifi. I have no connection to it.

I'm using the last 1.3.2 firmware version.
I tested with multiple powers, computer, phone charger etc ...
I verified with a multimeter, I have my 5V on the pins of my wemos, but I also have power on my shield etc ...
I don't know what I'm doing wrong ..
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

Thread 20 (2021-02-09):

Calibration how to

drybrdl, 2021-02-09:
Hi,
  is it possible to add a small "how to" for the calibration to the readme file. The link in the app for the Current_Transformer_Conditioner calibration doesnt really make much sense as its not the same device.
Im sure a quick "how to" for working out your settings would be helpful to alot of people including myself

Thanks for the great work

alcar21, 2021-03-21:
Ok, when I have a bit little time, I update the readme with the calibration section.
The best value for the calibration is the average consumption of your house or devices that you monitor.

alcar21, 2021-04-03:
@wladimir79 you can view the ICAL value in http://lechacal.com/wiki/index.php/Current_Transformer_Conditioner

CT | Output Type | Rburden | Rgain (for 5V) | ICAL (for 5V) | Rgain (for 3.3V) | ICAL (for 3.3V)
-- | -- | -- | -- | -- | -- | --
SCT-013-005 | Voltage | None | 130 kΩ | 2.83 | None* | 5.0
SCT-013-010 | Voltage | None | 130 kΩ | 5.66 | None* | 10.0
SCT-013-015 | Voltage | None | 130 kΩ | 8.49 | None* | 15.0
SCT-013-020 | Voltage | None | 130 kΩ | 11.31 | None* | 20.0
SCT-013-025 | Voltage | None | 130 kΩ | 14.14 | None* | 25.0
SCT-013-030 | Voltage | None | 130 kΩ | 16.96 | None* | 30.0
SCT-013-050 | Voltage | None | 130 kΩ | 28.28 | None* | 50.0
SCT-013-060 | Voltage | None | 130 kΩ | 33.94 | None* | 60.0
  |   |   |   |  
SCT-006 | Current | 10 Ω | 17 kΩ | 11.62 | 28 kΩ | 17.5
SCT-013-000 | Current | 10 Ω | 40 kΩ | 56.57 | 75 kΩ | 85.71
SCT-019 | Current | 10 Ω | 24 kΩ | 116.13 | 40 kΩ | 171.43

wladimir79, 2021-04-05:
I saw this link, but I did not know whether to take the value for 3v or 5v sorry

alcar21, 2021-04-05:
My apologies, It's value of 5v.

wladimir79, 2021-04-05:
thanks 😉

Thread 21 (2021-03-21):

Mqtt Problem

wladimir79, 2021-03-21:
Hi,
i configured MQTT Parameters and from Mosquitto broker logs the device is connected.
```
1616335675: Client wemosEM-4E7EF6 already connected, closing old connection.
1616335675: New client connected from 192.168.1.54 as wemosEM-4E7EF6 (p2, c1, k30, u'mqtt_user').
```

The entity created on Hassio always returns UNKNOWN
this code is in sensors.yaml

```
- platform: mqtt
  state_topic: "wemos/wemosem-4e7ef6/power"
  name: "EM General A"
  icon: mdi:current-ac
  unit_of_measurement: "A"
  value_template: "{{ value_json.current }}"
- platform: mqtt
  state_topic: "wemos/wemosem-4e7ef6/power"
  name: "EM General W"
  icon: mdi:power-plug
  unit_of_measurement: "W"
  value_template: "{{ value_json.watios }}"
- platform: mqtt
  state_topic: "wemos/wemosem-4e7ef6/power"
  name: "EM General KWh"
  icon: mdi:power-plug
  unit_of_measurement: "KWh"
  value_template: "{{ value_json.kwh }}"
```

Where am I doing wrong?

thx

mason-xx, 2021-03-21:
why do you even need the yaml config? hassio is able to autodiscover mqtt devices and creates the entities for you?
Just remove it completly and check the mqtt integration in hassio.

wladimir79, 2021-03-21:
I have other device configured without autodiscover and I do not have any problem.
The entity in hassio is created and in the mosquitto logs is connected correctly

the only problem is that the value is not read, how can I be sure that it is sent by the Wemos?

mason-xx, 2021-03-21:
did you check if mqtt is recieving it? just subscribe to the topic and look how the payload looks

wladimir79, 2021-03-21:
i try with topic in the manual (wemos/wemosEM-XXXXXX/power), you see my config in the first post

Check the subscribe from hassio and from chrome addon but not received data 😔

mason-xx, 2021-03-21:
maybe check with just some toollike  https://mqttfx.jensd.de/ this show you your whole traffic on the server...

alcar21, 2021-03-21:
Hello, Sorry, i have no time for this project. I want to help you.

You can use MQTT Explorer too, it's a good program for explorer your MQTT topics.

Your config is wrong. Test the next config:
```
- platform: mqtt
  state_topic: "wemos/wemosEM-4E7EF6/power"
  name: "EM General A"
  icon: mdi:current-ac
  unit_of_measurement: "A"
  value_template: "{{ value_json.current }}"
- platform: mqtt
  state_topic: "wemos/wemosEM-4E7EF6/power"
  name: "EM General W"
  icon: mdi:power-plug
  unit_of_measurement: "W"
  value_template: "{{ value_json.watios }}"
- platform: mqtt
  state_topic: "wemos/wemosEM-4E7EF6/power"
  name: "EM General KWh"
  icon: mdi:power-plug
  unit_of_measurement: "KWh"
  value_template: "{{ value_json.kwh }}"
```
The config of home assistant is case sensitive.

wladimir79, 2021-03-21:
thank you so much, I didn't know about case sensitive

now everything works correctly :-)

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

Closed 2021-03-21.

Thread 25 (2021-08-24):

Energy integration Home Assistant

Watanakas, 2021-08-24:
Someone is using this meter with the new Hassio version with the energy integration, the sensors do not appear, they can explain if it works for them and how they have done it, thank you.

mason-xx, 2021-08-24:
just use a template sensor, i have 3 wemosEM running one for one phase in my flat and add them up in one sensor:

```
- platform: template
    sensors:
      energy_total:
        friendly_name: 'Total Energy'
        value_template: "{{ float(states('sensor.wemosem_xxxxx_kwh')) + float(states('sensor.wemosem_xxxxx_kwh')) + float(states('sensor.wemosem_xxxxx_kwh')) |round(5) }}"
        unit_of_measurement: 'kWh'
        device_class: energy
```

then just use the utility source and you can select is as a unit in the energy meter:

```
utility_meter:
  energy:
    source: sensor.energy_total
    cycle: yearly
```

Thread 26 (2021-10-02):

Network connection problems

Watanakas, 2021-10-02:
The device is working correctly but when the network goes down, it does not reconnect to the wifi network, I have to turn the device off and on, it is not often if I do not check it it remains without connecting to the network,
I lose information, do you have solution?

alcar21, 2021-10-03:
Do you have the last version?

Watanakas, 2021-10-21:
Working perfect with this latest version, thanks.

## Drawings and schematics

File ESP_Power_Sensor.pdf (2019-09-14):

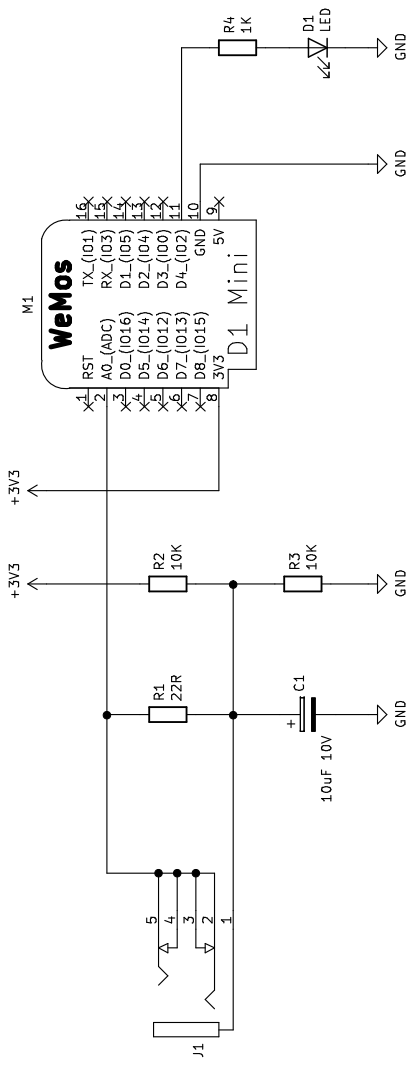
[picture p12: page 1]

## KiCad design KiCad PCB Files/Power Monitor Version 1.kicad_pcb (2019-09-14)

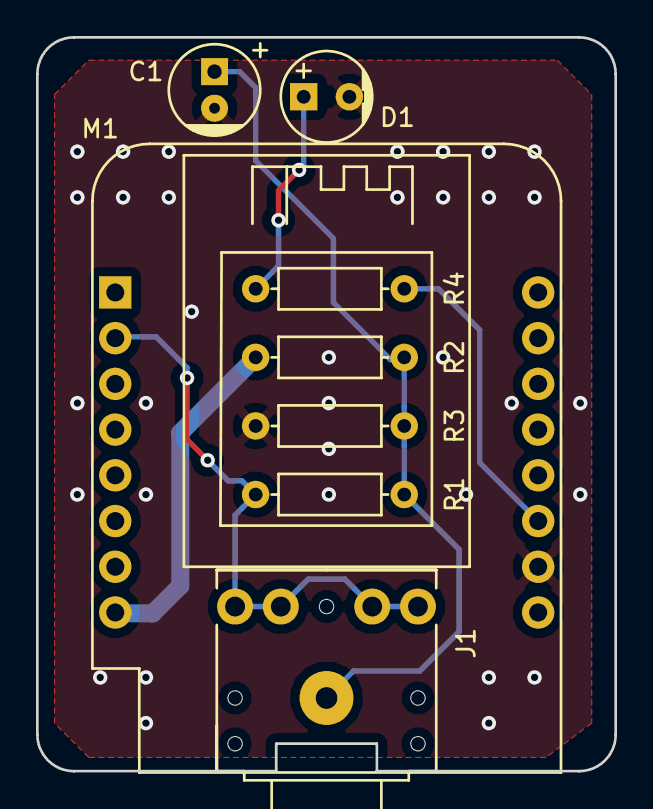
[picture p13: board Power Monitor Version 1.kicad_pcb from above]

Board: 2 copper layers, 32.1 x 40.8 mm, 8 parts (0 on the bottom side), 6 nets.

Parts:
C1: 10uF 10V; Cap_5mm_THT
D1: LED; LED 5mm
J1: 3.5mm Jack Socket - PJ-307; Jack_3.5_PJ-307
M1: Wemos_D1_Mini; Wemos D1 Mini
R1: 22R; Resistor_THT
R2, R3: 10K; Resistor_THT
R4: 1K; Resistor_THT

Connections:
+3V3: M1.8, R2.1
GND: C1.2, D1.2, M1.10, R3.2
unnamed: C1.1, J1.1, R1.2, R2.2, R3.1
unnamed: D1.1, R4.2
unnamed: J1.2, J1.3, J1.4, J1.5, M1.2, R1.1
unnamed: M1.11, R4.1

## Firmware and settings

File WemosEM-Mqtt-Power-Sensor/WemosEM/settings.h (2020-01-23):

/*
  Default parameters, settings load and save functions

  Alfonso C. Alvarez (Alcar), 14nd September 2019

  @author <a href="mailto:alcar21@gmail.com">Alfonso Carlos Alvarez Reyes</a>

  Compile with Arduino 2.4.2
*/

#define DEFAULT_EMPTY ""

// WIFI
#define DEFAULT_WIFI_NAME ""
#define DEFAULT_WIFI_PASSWORD ""
#define DEFAULT_IP_MODE 0 //  0 = DHCP, 1 = Static
#define DEFAULT_IP ""
#define DEFAULT_MASK ""
#define DEFAULT_GATEWAY ""
// MQTT
#define DEFAULT_MQTT_SERVER "192.168.1.2"
#define DEFAULT_MQTT_PORT 1883
#define DEFAULT_MQTT_USERNAME ""
#define DEFAULT_MQTT_PASSWORD ""
// CALIBRATE
#define DEFAULT_MESSAGE_INTERVAL 10000
#define DEFAULT_VOLTAGE 225.0
#define DEFAULT_ICAL 30.50
// TIMEZONE
#define DEFAULT_TIMEZONE 1
#define DEFAULT_MINUTES_TIMEZONE 0
// SYSTEM
#define DEFAULT_SYSTEM_USER "wemosem"
#define DEFAULT_SYSTEM_PASSWORD "infinito&masalla"

// VARIABLES
String system_password = DEFAULT_SYSTEM_PASSWORD;
int ipMode = DEFAULT_IP_MODE; // 0 = DHCP, 1 = Static

// Add your Wifi details below. Set SSID to NULL if unused.
// WiFi slot 1
String wifi_name = DEFAULT_WIFI_NAME;
String wifi_password =  DEFAULT_WIFI_PASSWORD;
String ip =  DEFAULT_IP;
String mask = DEFAULT_MASK;
String gateway = DEFAULT_GATEWAY;

// MQTT Broker address and port
boolean mqtt_enabled = false;
String mqtt_server = DEFAULT_MQTT_SERVER;
int mqtt_port = 1883;
String mqtt_username = DEFAULT_MQTT_USERNAME;
String mqtt_password = DEFAULT_MQTT_PASSWORD;

int message_interval = DEFAULT_MESSAGE_INTERVAL;     // Time in ms between each message. 5000 ms = 5 seconds

// Mains voltage and calibration
float mainsVoltage = DEFAULT_VOLTAGE;          // Mains voltage in Volts. Change this value according to your mains.
float Ical = DEFAULT_ICAL;             // Varia dentro del mismo fabricante, hay que calibrarlo (1800 vueltas del secundario STC013 / 69 Ohm resistencia carga (burden)) = 26.1

// Iot Platforms
// Blynk platform
boolean blynk_enabled = false;
String blynkAuth = DEFAULT_EMPTY;
String blynkServer = DEFAULT_EMPTY;
uint16_t blynkPort = 0;

// ThingSpeak platform
boolean thingSpeak_enabled = false;
unsigned long tsChannelNumber = 0;
String tsWriteAPIKey = DEFAULT_EMPTY;

// TimeZone
int8_t timeZone = DEFAULT_TIMEZONE;
int8_t minutesTimeZone = DEFAULT_MINUTES_TIMEZONE;

// Date RESET
int dayReset = 0;

boolean loadConfig() {

  String jsonString;

  if (!SPIFFS.begin()) {
    Serial.println("ERROR: Failed to mount file system");
    return false;
  }

  File configFile = SPIFFS.open("/config.json", "r");
  if (!configFile) {
    Serial.println("ERROR: Failed to open config file");
    return false;
  }

  size_t size = configFile.size();
  // if (size > 1024) {
  //   Serial.println("ERROR: Config file size is too large");
  //   return false;
  // }

  // Allocate a buffer to store contents of the file.
  std::unique_ptr<char[]> buf(new char[size]);

  // We don't use String here because ArduinoJson library requires the input
  // buffer to be mutable. If you don't use ArduinoJson, you may as well
  // use configFile.readString instead.
  configFile.readBytes(buf.get(), size);

  DynamicJsonDocument jsonConfig(1024);
  auto error = deserializeJson(jsonConfig, buf.get());
  if (error) {
    Serial.println("Failed to parse config file");
    return false;
  }

  serializeJson(jsonConfig, jsonString);
  Serial.println("LOADED CONFIG: " + jsonString);

  // WIFI
  wifi_name = (jsonConfig["wifi_name"] == "" ? DEFAULT_WIFI_NAME : jsonConfig["wifi_name"].as<String>());
  wifi_password = (jsonConfig["wifi_password"] == "" ? DEFAULT_WIFI_PASSWORD : jsonConfig["wifi_password"].as<String>());
  ipMode = (jsonConfig["ip_mode"] == "" ? DEFAULT_IP_MODE : jsonConfig["ip_mode"]);
  ip = (jsonConfig["ip"] == "" ? DEFAULT_IP : jsonConfig["ip"].as<String>());
  mask = (jsonConfig["mask"] == "" ? DEFAULT_MASK : jsonConfig["mask"].as<String>());
  gateway = (jsonConfig["gateway"] == "" ? DEFAULT_GATEWAY : jsonConfig["gateway"].as<String>());
  // MQTT
  mqtt_enabled = (jsonConfig["mqtt_enabled"]);
  mqtt_server = (jsonConfig["mqtt_server"] == "" ? DEFAULT_MQTT_SERVER : jsonConfig["mqtt_server"].as<String>());
  mqtt_port = (jsonConfig["mqtt_port"] == "" ? DEFAULT_MQTT_PORT : jsonConfig["mqtt_port"]);
  mqtt_username = (jsonConfig["mqtt_username"] == "" ? DEFAULT_MQTT_USERNAME : jsonConfig["mqtt_username"].as<String>());
  mqtt_password = (jsonConfig["mqtt_password"] == "" ? DEFAULT_MQTT_PASSWORD : jsonConfig["mqtt_password"].as<String>());
  // CALIBRATE
  message_interval = (jsonConfig["message_interval"] == "" ? DEFAULT_MESSAGE_INTERVAL : jsonConfig["message_interval"]);
  mainsVoltage = (jsonConfig["voltage"] == "" ? DEFAULT_VOLTAGE : jsonConfig["voltage"]);
  Ical = (jsonConfig["ical"] == "" ? DEFAULT_ICAL : jsonConfig["ical"]);
  // IOT PLATFORMS
  blynk_enabled = (jsonConfig["blynk_enabled"] == 1 ? true : false);
  blynkAuth = (jsonConfig["blynkAuth"] == "" || jsonConfig["blynkAuth"] == "null" ? DEFAULT_EMPTY : jsonConfig["blynkAuth"].as<String>());
  blynkServer = (jsonConfig["blynkServer"] == "" || jsonConfig["blynkServer"] == "null" ? DEFAULT_EMPTY : jsonConfig["blynkServer"].as<String>());
  blynkPort = (jsonConfig["blynkPort"] == "" ? DEFAULT_MQTT_PORT : jsonConfig["blynkPort"]);

  thingSpeak_enabled = (jsonConfig["ts_enabled"] == 1 ? true : false);
  tsChannelNumber = (jsonConfig["tsChannelNumber"] == "" ? 0 : jsonConfig["tsChannelNumber"]);
  tsWriteAPIKey = (jsonConfig["tsWriteAPIKey"] == "" || jsonConfig["tsWriteAPIKey"] == "null" ? DEFAULT_EMPTY : jsonConfig["tsWriteAPIKey"].as<String>());

  // SYSTEM - TIMEZONE
  timeZone = (jsonConfig["timezone"] == "" ? DEFAULT_TIMEZONE : jsonConfig["timezone"]);
  minutesTimeZone = (jsonConfig["minutes_timezone"] == "" ? DEFAULT_MINUTES_TIMEZONE : jsonConfig["minutes_timezone"]);
  // SYSTEM
  system_password = (jsonConfig["system_password"] == "" ? DEFAULT_SYSTEM_PASSWORD : jsonConfig["system_password"].as<String>());
  dayReset = (jsonConfig["dayReset"] == "" ? 0 : jsonConfig["dayReset"]);

  // KWH
  watiosTotal = (jsonConfig["watiosTotal"] == "" ? 0.0 : jsonConfig["watiosTotal"]);
  kiloWattHours = (jsonConfig["kiloWattHours"] == "" ? 0.0 : jsonConfig["kiloWattHours"]);
  beforeResetKiloWattHours = (jsonConfig["beforeResetKiloWattHours"] == "" ? 0.0 : jsonConfig["beforeResetKiloWattHours"]);

  return true;

}

bool saveConfig() {
  DynamicJsonDocument jsonConfig(1024);
  String jsonString;

    // WIFI
  jsonConfig["wifi_name"] = wifi_name;
  jsonConfig["wifi_password"] = wifi_password;
  jsonConfig["ip_mode"] = ipMode;
  jsonConfig["ip"] = ip;
  jsonConfig["mask"] = mask;
  jsonConfig["gateway"] = gateway;
  // MQTT
  jsonConfig["mqtt_enabled"] = mqtt_enabled;
  jsonConfig["mqtt_server"] = mqtt_server;
  jsonConfig["mqtt_port"] = mqtt_port;
  jsonConfig["mqtt_username"] = mqtt_username;
  jsonConfig["mqtt_password"] = mqtt_password;
  // CALIBRATE
  jsonConfig["message_interval"] = message_interval;
  jsonConfig["voltage"] = mainsVoltage;
  jsonConfig["ical"] = Ical;

  // IOT PLATFORMS
  jsonConfig["blynk_enabled"] = blynk_enabled;
  jsonConfig["blynkAuth"] = blynkAuth;
  jsonConfig["blynkServer"] = blynkServer;
  jsonConfig["blynkPort"] = blynkPort;

  jsonConfig["ts_enabled"] = thingSpeak_enabled;
  jsonConfig["tsChannelNumber"] = tsChannelNumber;
  jsonConfig["tsWriteAPIKey"] = tsWriteAPIKey;

  // SYSTEM - TIMEZONE
  jsonConfig["timezone"] = timeZone;
  jsonConfig["minutes_timezone"] = minutesTimeZone;
  // SYSTEM
  jsonConfig["system_password"] = system_password;
  jsonConfig["dayReset"] = dayReset;


  // KWH
  jsonConfig["watiosTotal"] = watiosTotal;
  jsonConfig["kiloWattHours"] = kiloWattHours;
  jsonConfig["beforeResetKiloWattHours"] = beforeResetKiloWattHours;

  File configFile = SPIFFS.open("/config.json", "w");
  if (!configFile) {
    Serial.println("Failed to open config file for writing");
    return false;
  }

  serializeJson(jsonConfig, configFile);
  serializeJson(jsonConfig, jsonString);
  Serial.println("SAVED CONFIG: " + jsonString);
  return true;
}

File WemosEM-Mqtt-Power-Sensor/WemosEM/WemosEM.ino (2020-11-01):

/*
  MQTT with ESP8266 and Power Monitor 5th December 2017
  David Mottram
  Updated by Alfonso C. Alvarez (Alcar), 14nd September 2019

  @author <a href="mailto:alcar21@gmail.com">Alfonso Carlos Alvarez Reyes</a>

  Compile with Arduino 2.4.2
*/

#include <ESP8266WiFi.h>
#include <DNSServer.h>            //Local DNS Server used for redirecting all requests to the configuration portal
#include <ESP8266WebServer.h>     //Local WebServer used to serve the configuration portal
#include <WiFiManager.h>
#include <PubSubClient.h>
#include <NtpClientLib.h>
#include <EmonLib.h>
#include <ESP8266mDNS.h>
#include <ESP8266HTTPUpdateServer.h>
#include <FS.h>
#include <ArduinoJson.h>
#include <BlynkSimpleEsp8266.h>
#include <ThingSpeak.h>
#include <ArduinoOTA.h>

#include "WiFiClientPrint.h"
#include "variables.h"
#include "settings.h"
#include "ntp_support.h"
#include "mqtt_wifi_serial_support.h"
#include "iot_platforms_support.h"
#include "power_meter_support.h"
#include "webserver_support.h"

// Initial setup
void setup(void) {

  delay(10);

  prepareHostMacAndEvents();

  pinMode(Status_LED, OUTPUT);                // Initialize Status LED
  Status_LED_Off;

  initSerial();

  loadConfig();

  setupWifi();

  emon.current(A0, Ical);             // Current: input pin A6=D4, calibration factor

  initMqtt();

  randomSeed(micros());

  ms_since_last_message = millis();           // Reset time since sending last message

  setup_http_server();

  setup_blynk();

  setup_thingspeak();

  setupOTA();

  emon.current(A0, Ical);
  em_read(true);

  Serial.println("Setup finished");
} // End of setup


// main loop
void loop() {

  ArduinoOTA.handle();

  ntp_loop();

  em_loop();

  if (WiFi.status() != WL_CONNECTED) {
    Serial.println("WiFi connection lost!");
    ESP.restart();
    delay(100);
  }

  mqtt_client.loop();
  httpServer.handleClient(); //handles requests for the firmware update page

  if (resetESP) {
    WiFi.persistent(true); // use SDK storage of SSID/WPA parameters
    WiFi.disconnect(); // this will store empty ssid/wpa into sdk storage
    WiFi.persistent(false); // Do not use SDK storage of SSID/WPA parameters
    Serial.println("formatting...");
    SPIFFS.format();
    ESP.restart();
    delay(100);
  }

  if (restartESP) {
    ESP.restart();
    delay(100);
  }

} // End of main loop

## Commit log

2019-09-14 First version
    [Power Monitor Version 1-B.Cu.gbr, Power Monitor Version 1-B.Mask.gbr, Power Monitor Version 1-B.Paste.gbr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]
2019-10-07 #1 Fixed compiler with arduino 2.3.0
2019-10-09 Create three profiles to compile: - arduino core 2.3 - arduino core 2.4 - arduino core 2.5 Improved web performance
2019-11-04 - Blynk Integration - ThingSpeak integration - Improvement Wifi connection - Optional reset Kwh counter one day of the month - Added parameter with previous kilowatts before reset - Improvement on we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
    [WemosEM.ino, settings.h, variables.h]
